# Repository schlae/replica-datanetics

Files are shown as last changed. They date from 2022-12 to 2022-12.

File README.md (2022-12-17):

# Replica Datanetics Keyboard

Do you need a Datanetics ASCII keyboard for your computer project (such as a replica Apple 1)? Don't want to pay high prices for an original Datanetics keyboard? Then consider building this replica.

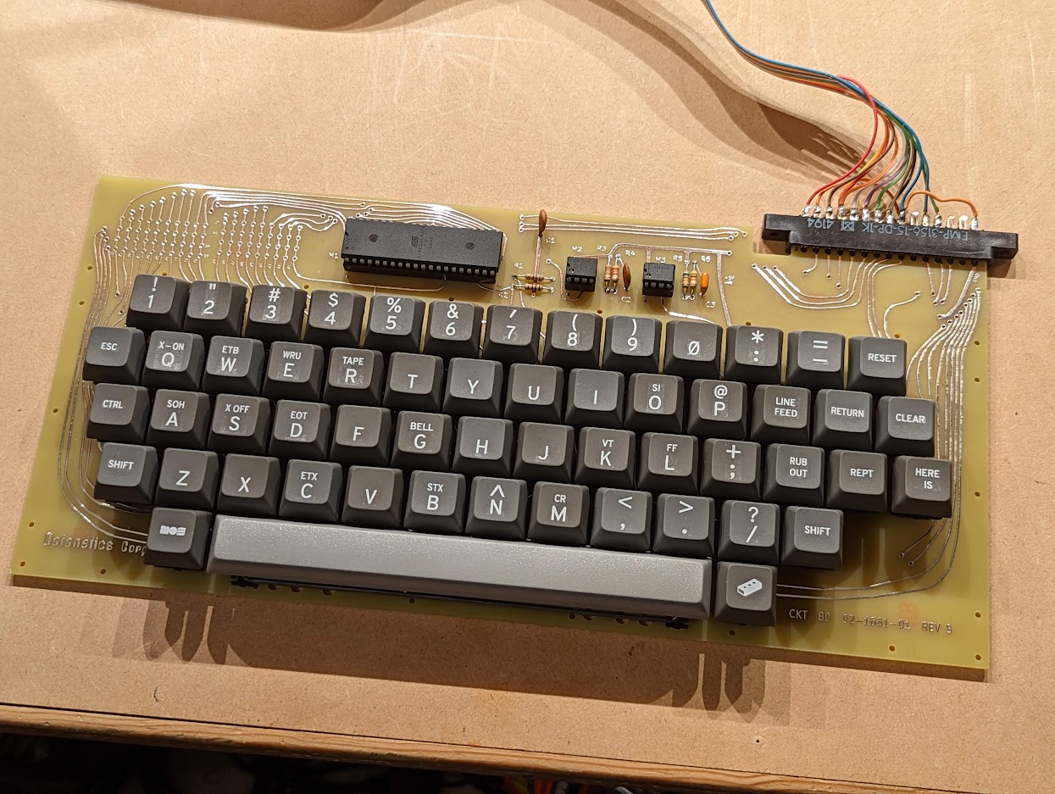
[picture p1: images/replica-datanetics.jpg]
Replica Datanetics keyboard photo


This is not the first replica Datanetics keyboard. Mike Willegal [designed one](http://www.willegal.net/appleii/apple1-datanetics.htm). In fact, I started with his design and redid it using KiCad. Instead of using the expensive, fragile, and hard-to-find MM5740 keyboard chip, I switched to a more common microcontroller: the ATMega644P. I also removed the output buffer chips--just in case you want to redo my firmware and implement some other keyboard protocol, you'll be able to control the pin direction.

Here are the design files. The BOM does not include manufacturer part numbers because it uses very common through hole parts that you might already have. The key switches are standard Cherry MX and are available from a wide variety of sources.

[Schematic](https://github.com/schlae/replica-datanetics/blob/main/Apple1Keyb.pdf)

[Bill of Materials](https://github.com/schlae/replica-datanetics/blob/main/Apple1Keyb.csv)

[Fab Files](https://github.com/schlae/replica-datanetics/blob/main/fab/Apple1Keyb_Rev1.zip)

[Water Slide Decal Graphics](https://github.com/schlae/replica-datanetics/blob/main/keycaps.svg)

## Fabrication and Assembly Notes

The circuit board is a 2-layer board, 11.75 by 5.5 inches (298.5 x 139.7mm). No special edge connector plating or bevel is needed. To make the board look like the original, order the board "bare bones" with no solder mask or silkscreen.

**Caution: There is a "matrix" via area in the upper left corner of the board with 76 non-plated vias. The drill locations for these are included in the "Apple1Keyb-NPTH.drl" file in the fab package. The User Comments layer also includes a note to the fab vendor to NOT plate these holes. You may want to add an extra comment to your fab vendor when you put in the order that these 76 holes must not be plated.**

To assemble the board, just solder in the components. I'd recommend using a socket for the U1 microcontroller so that you can reprogram it later. The NE555 timer (U2) in the original design was meant to provide the clock for the MM5740 chip, but isn't necessary in this design. You can install it or leave it out.

The second NE555 timer (U3) is necessary for the key repeat function.

## Key Caps

The keyboard design uses standard Cherry MX key switches and keycaps are available from numerous sources. For my own build, I used DSA keycaps along with an 8U spacebar from PMK. I looked into a number of ways of putting the legends on the keycaps but I ended up having some water slide decals custom made. See the file above if you want to use this same file, but I'd recommend putting the legends closer together so they'll fit on a smaller sheet, saving you money.

## Matrix Via Area

The Datanetics design has four key switches that are not connected to the key scanning matrix and are brought out to individual pins on the edge connector. If you're building an Apple 1, you'll want to use two of these keys for the reset and clear screen functions. 

If you want keys to be included in the scanning matrix, you'll want to solder a fine wire through the appropriate via in the upper left corner of the board. To find out which key will be generated, look up the row and column number in the key\_rom array in firmware source code. You can, of course, customize the generated key by editing the source and recompiling.

## Firmware

The firmware is designed for the ATMega644P microcontroller, but it should be possible to modify it to work with other 40-pin microcontrollers in the ATMega family. The prebuilt firmware behaves like a stock MM5740.

[Prebuilt Firmware](https://github.com/schlae/replica-datanetics/blob/main/fw/apple1keyb.hex)

Be sure to set the fuse bits of the ATMega644P according to the fuses.conf file:

```
lfuse = 0x62
hfuse = 0xdd
efuse = 0xfc
```

You can build the firmware yourself pretty easily. Under Ubuntu, install the `gcc-avr` package, and build the firmware by going to the directory and typing `make`.

If you have a minipro programmer (TL866 etc) you can program the device by typing `make fuses` followed by `make prog`. For this to work correctly, you'll need the [minipro software](https://gitlab.com/DavidGriffith/minipro) installed. You could also use the Windows minipro software from the manufacturer, or another programmer entirely.

## Mechanical Brackets

[Mike Willegal's site](http://www.willegal.net/appleii/apple1-datanetics.htm) has drawings for a mechanical bracket.

## Connecting to an Apple 1

If you want to connect this keyboard to an Apple 1, you can use the following wiring diagram. The connector to use is a 30-pin 0.156" edge connector, something like EDAC 305-030-520-202 or equivalent. The DIP plug is an insulation displacement connector, something like CW CWR-130-16-0001 or equivalent.

| Edge connector pin | Description | DIP plug pin |
|---|---|---|
| A | No connect (was -12V) | 11 (-12V) |
| B | Data bit 6 | 7 (B6) |
| C | Data bit 5 | 6 (B5) |
| D | Data bit 4 | 2 (B4) |
| E | Data bit 1 | 5 (B1) |
| F | Data bit 2 | 4 (B2) |
| H | Data bit 3 | 3 (B3) |
| J | Reset key | 1 (Reset) |
| K | Reset key | 9 (Gnd) |
| L | No connect (was OE) | No connect |
| M | Strobe | 14 (Str) |
| N | Data bit 7 | 8 (B7) |
| P | Data bit 8 | No connect |
| R | No connect (was data bit 9) | No connect |
| S | Ground | 9 |
| 1 | No connect | |
| 2 | No connect | |
| 3 | No connect | |
| 4 | +5V | 15, 16 |
| 5 | No connect | |
| 6 | No connect | |
| 7 | No connect | |
| 8 | Extra key 4 | 12 (Clr) |
| 9 | Extra key 4 | 16 |
| 10 | Extra key 3 | |
| 11 | Extra key 3 | |
| 12 | Extra key 1 | |
| 13 | Extra key 1 | |
| 14 | Extra key 2 | |
| 15 | Extra key 2 | |

## License
This work is licensed under a Creative Commons Attribution-ShareAlike 4.0
International License. See [https://creativecommons.org/licenses/by-sa/4.0/](https://creativecommons.org/licenses/by-sa/4.0/).

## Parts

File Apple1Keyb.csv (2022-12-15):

Item | Qty | Reference(s) | Value
1 | 1 | C1 | 0.1uF
2 | 1 | C2 | 0.01uF
3 | 1 | C3 | 0.68uF
4 | 2 | R1, R2 | 100
5 | 1 | R3 | 360
6 | 1 | R4 | 3.6K
7 | 1 | R5 | 510K
8 | 1 | R6 | 30K
9 | 56 | SW1-SW56 | Cherry MX keyswitch
10 | 2 |  | Cherry MX spacebar stabilizer
11 | 1 | U1 | ATmega644P-20P
12 | 2 | U2, U3 | NE555P

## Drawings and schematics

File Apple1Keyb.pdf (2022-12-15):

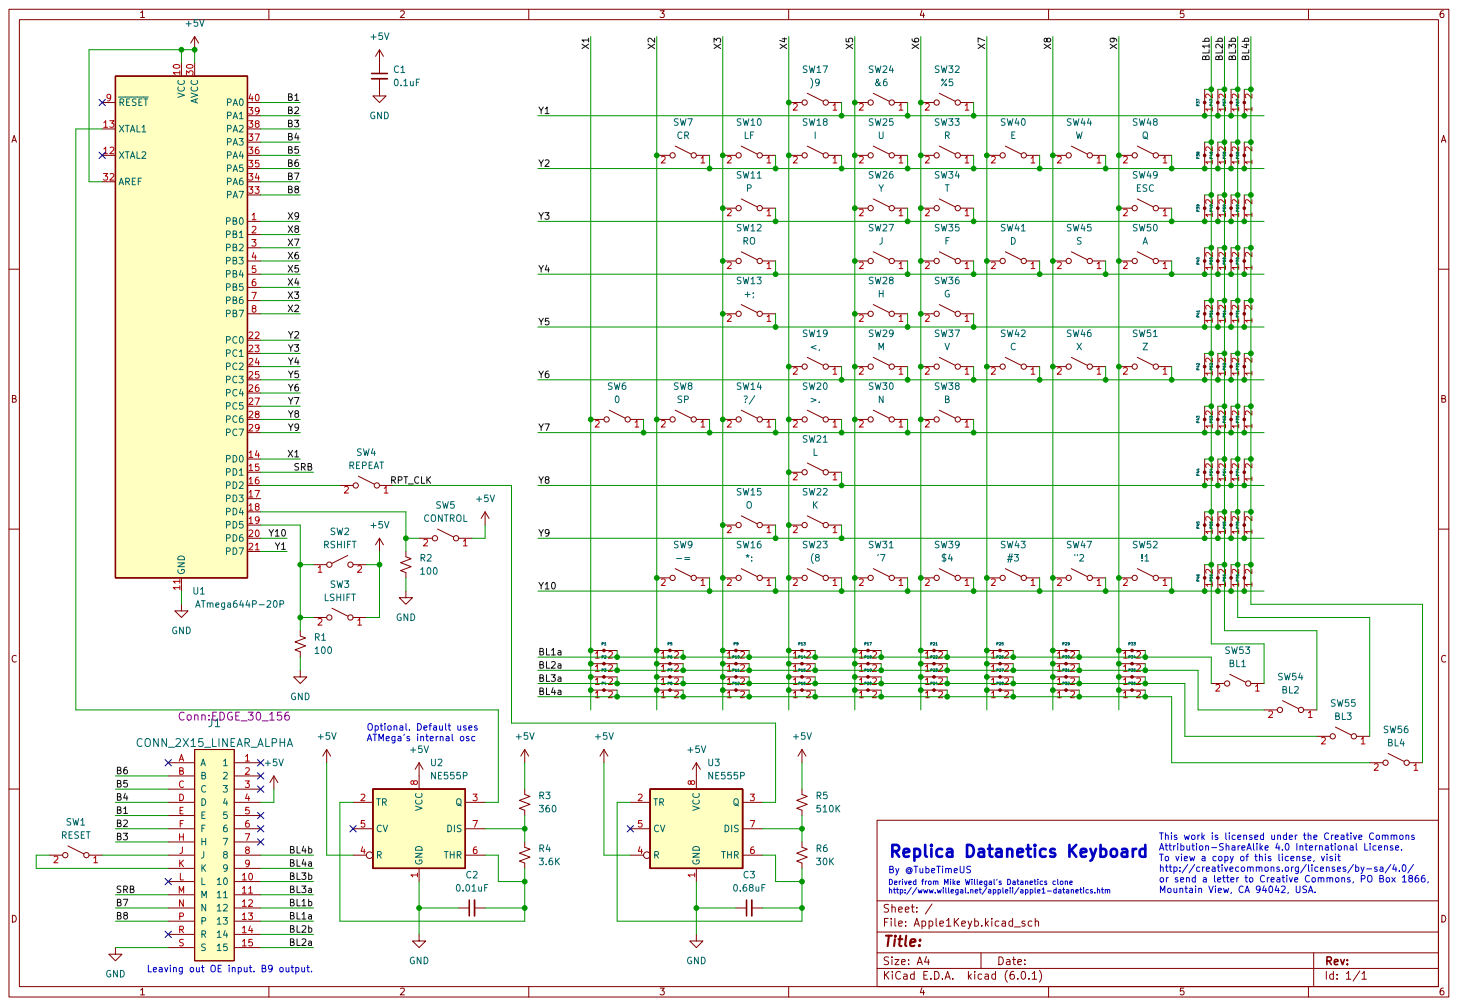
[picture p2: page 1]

This work is licensed under the Creative Commons Attribution-ShareAlike 4.0 International License. To view a copy of this license, visit

http://www.willegal.net/appleii/apple1-datanetics.htm By @TubeTimeUS

http://creativecommons.org/licenses/by-sa/4.0/ or send a letter to Creative Commons, PO Box 1866, Mountain View, CA 94042, USA.

Leaving out OE input. B9 output.

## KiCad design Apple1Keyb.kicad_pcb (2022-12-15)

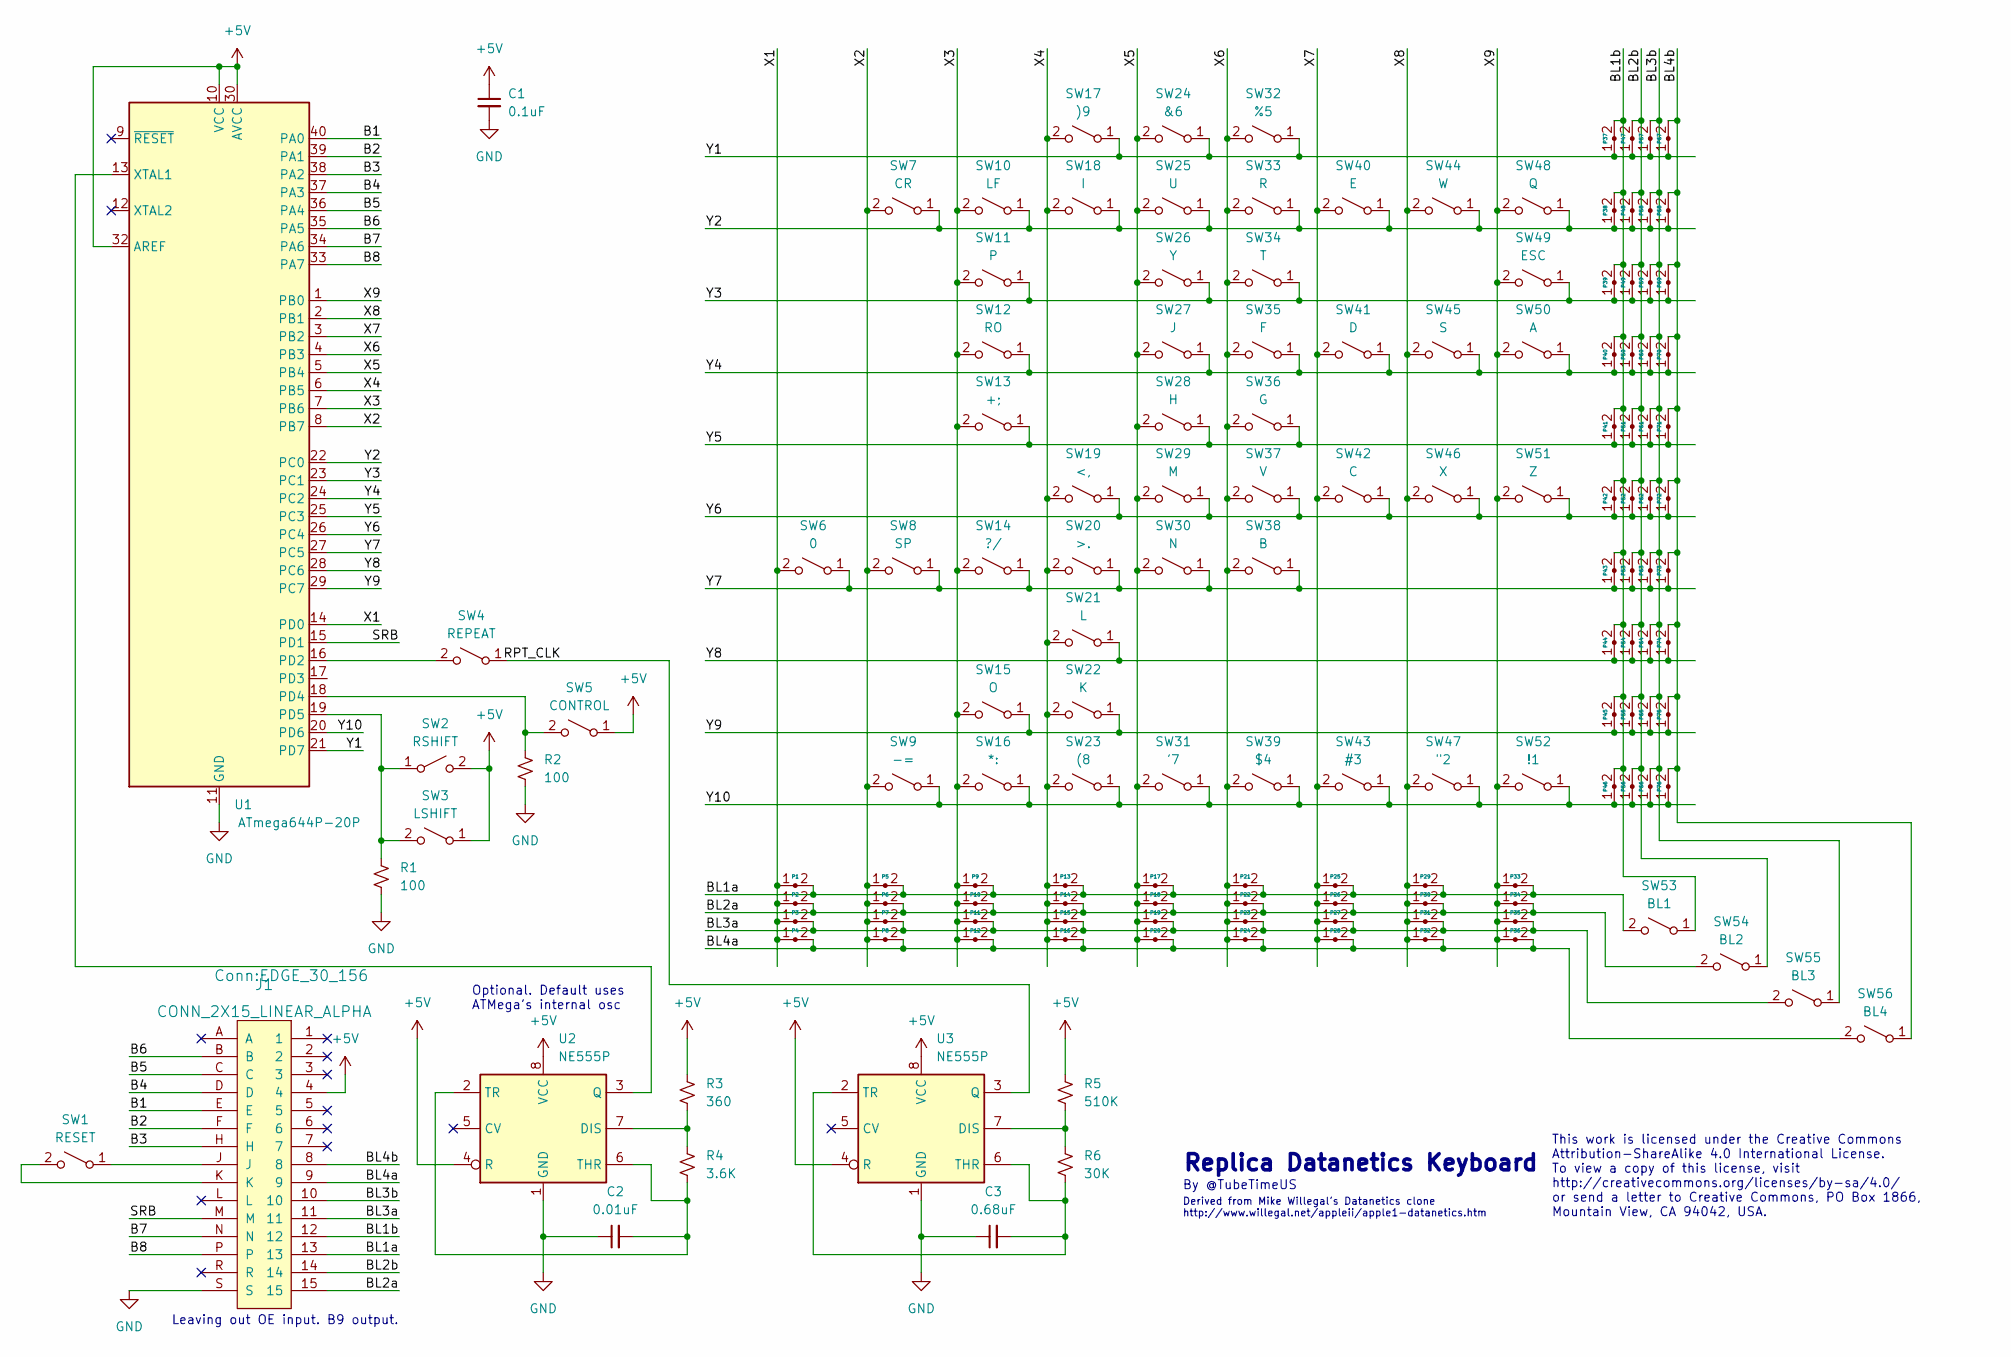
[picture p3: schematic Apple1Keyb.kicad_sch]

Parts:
C1: 0.1uF; C_Disc_D0.2in_W0.1in_P0.2in
C2: 0.01uF; C_Disc_D0.2in_W0.1in_P0.2in
C3: 0.68uF; C_Disc_D0.2in_W0.1in_P0.2in
J1: CONN_2X15_LINEAR_ALPHA; EDGE_30_156
P1, P2, P3, P4, P5, P6, P7, P8, P9, P10, P11, P12, P13, P14, P15, P16, P17, P18, P19, P20, P21, P22, P23, P24, P25, P26, P27, P28, P29, P30, P31, P32, P33, P34, P35, P36, P37, P38, P39, P40, P41, P42, P43, P44, P45, P46, P47, P48, P49, P50, P51, P52, P53, P54, P55, P56, P57, P58, P59, P60, P61, P62, P63, P64, P65, P66, P67, P68, P69, P70, P71, P72, P73, P74, P75, P76: jumper_pth; ViaNoPlate
R1, R2: 100; RESA500
R3: 360; RESA500
R4: 3.6K; RESA500
R5: 510K; RESA500
R6: 30K; RESA500
SW1: RESET; CHERRY_MX
SW2: RSHIFT; CHERRY_MX
SW3: LSHIFT; CHERRY_MX
SW4: REPEAT; CHERRY_MX
SW5: CONTROL; CHERRY_MX
SW6: 0; CHERRY_MX
SW7: CR; CHERRY_MX
SW8: SP; CHERRY_MX
SW9: -=; CHERRY_MX
SW10: LF; CHERRY_MX
SW11: P; CHERRY_MX
SW12: RO; CHERRY_MX
SW13: +;; CHERRY_MX
SW14: ?/; CHERRY_MX
SW15: O; CHERRY_MX
SW16: *:; CHERRY_MX
SW17: )9; CHERRY_MX
SW18: I; CHERRY_MX
SW19: <,; CHERRY_MX
SW20: >.; CHERRY_MX
SW21: L; CHERRY_MX
SW22: K; CHERRY_MX
SW23: (8; CHERRY_MX
SW24: &6; CHERRY_MX
SW25: U; CHERRY_MX
SW26: Y; CHERRY_MX
SW27: J; CHERRY_MX
SW28: H; CHERRY_MX
SW29: M; CHERRY_MX
SW30: N; CHERRY_MX
SW31: '7; CHERRY_MX
SW32: %5; CHERRY_MX
SW33: R; CHERRY_MX
SW34: T; CHERRY_MX
SW35: F; CHERRY_MX
SW36: G; CHERRY_MX
SW37: V; CHERRY_MX
SW38: B; CHERRY_MX
SW39: $4; CHERRY_MX
SW40: E; CHERRY_MX
SW41: D; CHERRY_MX
SW42: C; CHERRY_MX
SW43: #3; CHERRY_MX
SW44: W; CHERRY_MX
SW45: S; CHERRY_MX
SW46: X; CHERRY_MX
SW47: "2; CHERRY_MX
SW48: Q; CHERRY_MX
SW49: ESC; CHERRY_MX
SW50: A; CHERRY_MX
SW51: Z; CHERRY_MX
SW52: !1; CHERRY_MX
SW53: BL1; CHERRY_MX
SW54: BL2; CHERRY_MX
SW55: BL3; CHERRY_MX
SW56: BL4; CHERRY_MX
U1: ATmega644P-20P; DIP-40_W15.24mm
U2, U3: NE555P; DIP-8_W7.62mm

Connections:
+5V: C1.1, J1.4, R3.2, R5.2, SW2.2 (B), SW3.1 (A), SW5.1 (A), U1.10 (VCC), U1.30 (AVCC), U1.32 (AREF), U2.4 (R), U2.8 (VCC), U3.4 (R), U3.8 (VCC)
/B1: J1.E, U1.40 (PA0)
/B2: J1.F, U1.39 (PA1)
/B3: J1.H, U1.38 (PA2)
/B4: J1.D, U1.37 (PA3)
/B5: J1.C, U1.36 (PA4)
/B6: J1.B, U1.35 (PA5)
/B7: J1.N, U1.34 (PA6)
/B8: J1.P, U1.33 (PA7)
/BL1a: J1.13, P1.2, P5.2, P9.2, P13.2, P17.2, P21.2, P25.2, P29.2, P33.2, SW53.2 (B)
/BL1b: J1.12, P37.2, P38.2, P39.2, P40.2, P41.2, P42.2, P43.2, P44.2, P45.2, P46.2, SW53.1 (A)
/BL2a: J1.15, P2.2, P6.2, P10.2, P14.2, P18.2, P22.2, P26.2, P30.2, P34.2, SW54.2 (B)
/BL2b: J1.14, P47.2, P48.2, P49.2, P50.2, P51.2, P52.2, P53.2, P54.2, P55.2, P56.2, SW54.1 (A)
/BL3a: J1.11, P3.2, P7.2, P11.2, P15.2, P19.2, P23.2, P27.2, P31.2, P35.2, SW55.2 (B)
/BL3b: J1.10, P57.2, P58.2, P59.2, P60.2, P61.2, P62.2, P63.2, P64.2, P65.2, P66.2, SW55.1 (A)
/BL4a: J1.9, P4.2, P8.2, P12.2, P16.2, P20.2, P24.2, P28.2, P32.2, P36.2, SW56.2 (B)
/BL4b: J1.8, P67.2, P68.2, P69.2, P70.2, P71.2, P72.2, P73.2, P74.2, P75.2, P76.2, SW56.1 (A)
/RPT_CLK: SW4.1 (A), U3.3 (Q)
/SRB: J1.M, U1.15 (PD1)
/X1: P1.1, P2.1, P3.1, P4.1, SW6.2 (B), U1.14 (PD0)
/X2: P5.1, P6.1, P7.1, P8.1, SW7.2 (B), SW8.2 (B), SW9.2 (B), U1.8 (PB7)
/X3: P9.1, P10.1, P11.1, P12.1, SW10.2 (B), SW11.2 (B), SW12.2 (B), SW13.2 (B), SW14.2 (B), SW15.2 (B), SW16.2 (B), U1.7 (PB6)
/X4: P13.1, P14.1, P15.1, P16.1, SW17.2 (B), SW18.2 (B), SW19.2 (B), SW20.2 (B), SW21.2 (B), SW22.2 (B), SW23.2 (B), U1.6 (PB5)
/X5: P17.1, P18.1, P19.1, P20.1, SW24.2 (B), SW25.2 (B), SW26.2 (B), SW27.2 (B), SW28.2 (B), SW29.2 (B), SW30.2 (B), SW31.2 (B), U1.5 (PB4)
/X6: P21.1, P22.1, P23.1, P24.1, SW32.2 (B), SW33.2 (B), SW34.2 (B), SW35.2 (B), SW36.2 (B), SW37.2 (B), SW38.2 (B), SW39.2 (B), U1.4 (PB3)
/X7: P25.1, P26.1, P27.1, P28.1, SW40.2 (B), SW41.2 (B), SW42.2 (B), SW43.2 (B), U1.3 (PB2)
/X8: P29.1, P30.1, P31.1, P32.1, SW44.2 (B), SW45.2 (B), SW46.2 (B), SW47.2 (B), U1.2 (PB1)
/X9: P33.1, P34.1, P35.1, P36.1, SW48.2 (B), SW49.2 (B), SW50.2 (B), SW51.2 (B), SW52.2 (B), U1.1 (PB0)
/Y1: P37.1, P47.1, P57.1, P67.1, SW17.1 (A), SW24.1 (A), SW32.1 (A), U1.21 (PD7)
/Y2: P38.1, P48.1, P58.1, P68.1, SW7.1 (A), SW10.1 (A), SW18.1 (A), SW25.1 (A), SW33.1 (A), SW40.1 (A), SW44.1 (A), SW48.1 (A), U1.22 (PC0)
/Y3: P39.1, P49.1, P59.1, P69.1, SW11.1 (A), SW26.1 (A), SW34.1 (A), SW49.1 (A), U1.23 (PC1)
/Y4: P40.1, P50.1, P60.1, P70.1, SW12.1 (A), SW27.1 (A), SW35.1 (A), SW41.1 (A), SW45.1 (A), SW50.1 (A), U1.24 (PC2)
/Y5: P41.1, P51.1, P61.1, P71.1, SW13.1 (A), SW28.1 (A), SW36.1 (A), U1.25 (PC3)
/Y6: P42.1, P52.1, P62.1, P72.1, SW19.1 (A), SW29.1 (A), SW37.1 (A), SW42.1 (A), SW46.1 (A), SW51.1 (A), U1.26 (PC4)
/Y7: P43.1, P53.1, P63.1, P73.1, SW6.1 (A), SW8.1 (A), SW14.1 (A), SW20.1 (A), SW30.1 (A), SW38.1 (A), U1.27 (PC5)
/Y8: P44.1, P54.1, P64.1, P74.1, SW21.1 (A), U1.28 (PC6)
/Y9: P45.1, P55.1, P65.1, P75.1, SW15.1 (A), SW22.1 (A), U1.29 (PC7)
/Y10: P46.1, P56.1, P66.1, P76.1, SW9.1 (A), SW16.1 (A), SW23.1 (A), SW31.1 (A), SW39.1 (A), SW43.1 (A), SW47.1 (A), SW52.1 (A), U1.20 (PD6)
GND: C1.2, C2.1, C3.1, J1.S, R1.1, R2.1, U1.11 (GND), U1.31 (GND), U2.1 (GND), U3.1 (GND)
unnamed: C2.2, R4.1, U2.2 (TR), U2.6 (THR)
unnamed: C3.2, R6.1, U3.2 (TR), U3.6 (THR)
unnamed: J1.J, SW1.1 (A)
unnamed: J1.K, SW1.2 (B)
unnamed: R1.2, SW2.1 (A), SW3.2 (B), U1.19 (PD5)
unnamed: R2.2, SW5.2 (B), U1.18 (PD4)
unnamed: R3.1, R4.2, U2.7 (DIS)
unnamed: R5.1, R6.2, U3.7 (DIS)
unnamed: SW4.2 (B), U1.16 (PD2)
unnamed: U1.13 (XTAL1), U2.3 (Q)

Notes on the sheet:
By @TubeTimeUS
Leaving out OE input. B9 output.
Optional. Default uses ATMega's internal osc
Derived from Mike Willegal's Datanetics clone http://www.willegal.net/appleii/apple1-datanetics.htm
Replica Datanetics Keyboard
This work is licensed under the Creative Commons Attribution-ShareAlike 4.0 International License. To view a copy of this license, visit http://creativecommons.org/licenses/by-sa/4.0/ or send a letter to Creative Commons, PO Box 1866, Mountain View, CA 94042, USA.

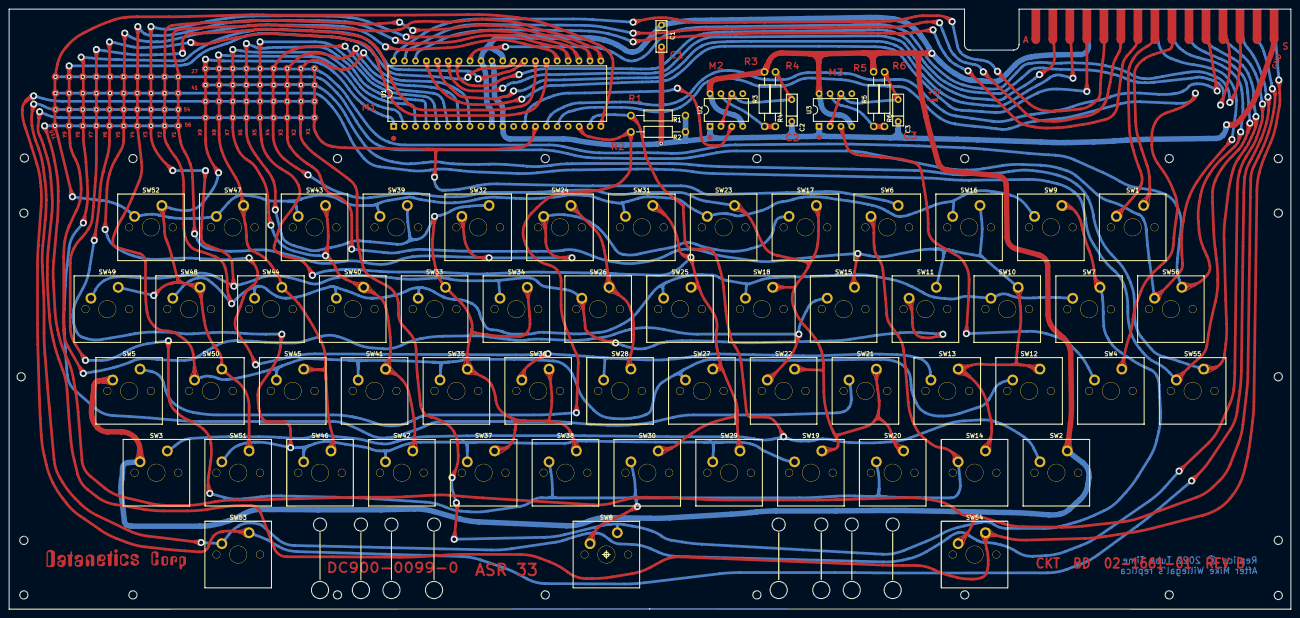
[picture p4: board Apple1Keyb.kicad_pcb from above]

Board: 2 copper layers, 298.4 x 139.7 mm, 169 parts (1 on the bottom side), 49 nets.

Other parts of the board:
G1: LOGO; Datanetics
MH1, MH2, MH3, MH4, MH5, MH6, MH7, MH8, MH9, MH10, MH11, MH12, MH13, MH14, MH15, MH16, MH17, MH18, MH19, MH20, MH21, MH22: MountHole
ST1: CHERRY_ST3

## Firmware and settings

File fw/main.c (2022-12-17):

/* MM5740 equivalent clone, copyright (C) 2022 Tube Time.

   This work is licensed under the Creative Commons Attribution-ShareAlike 4.0
   International License. To view a copy of this license, visit
   http://creativecommons.org/licenses/by-sa/4.0/ or send a letter to
   Creative Commons, PO Box 1866, Mountain View, CA 94042, USA.
*/

#include <stdbool.h>
#include <avr/io.h>
#include <util/delay.h>


/* Port assignments:
    PORTA = External data port (outputs)
    PORTB
        0 - X9
        1 - X8
        2 - X7
        3 - X6
        4 - X5
        5 - X4
        6 - X3
        7 - X2
    PORTC
        0 - Y2
        1 - Y3
        2 - Y4
        3 - Y5
        4 - Y6
        5 - Y7
        6 - Y8
        7 - Y9
    PORTD
        0 - X1
        1 - SRB (strobe output)
        2 - Repeat clock in
        3 - n/c
        4 - Control key
        5 - Shift key
        6 - Y10
        7 - Y1
*/

#define KEY_COUNT           90  // Total number of possible keys
#define DEBOUNCE_DELAY     200  // 2ms debounce delay
#define STROBE_TIME         50  // 50us strobe pulse
#define ROW_SETTLING_TIME   50  // 50us settling time

bool keyflags[KEY_COUNT] = {0};
bool repeat_history = false;

uint8_t key_rom[] = {
// Row
// 1     2     3     4     5     6     7     8     9   10
// Unshifted
 '8',  '4',  '5',  '1',  '2',  '3',  '0',  '6',  '9', '7', // Col 1
0x0c, 0x0d, 0x1c, 0x1d, 0x0b, 0x0e, 0x20, 0x09, 0x08, '-', // Col 2
 '0', 0x0a,  'P', 0x7f,  ';',  '.',  '/',  'P',  'O', ':', // Col 3
 '9',  'I',  'O',  'K',  'L',  ',',  '.',  'L',  'K', '8', // Col 4
 '6',  'U',  'Y',  'J',  'H',  'M',  'N',  'M',  'N', '7', // Col 5
 '5',  'R',  'T',  'F',  'G',  'V',  'B', 0x18, 0x19, '4', // Col 6
0x12,  'E', 0x13,  'D', 0x14,  'C', 0x15, 0x16, 0x17, '3', // Col 7
0x05,  'W', 0x06,  'S', 0x07,  'X', 0x0f, 0x10, 0x11, '2', // Col 8
0x00,  'Q', 0x1b,  'A', 0x01,  'Z', 0x02, 0x03, 0x04, '1', // Col 9

// Shifted
 '8',  '4',  '5',  '1',  '2',  '3',  '0',  '6',  '9', '7', // Col 1
0x0c, 0x0d, 0x1c, 0x1d, 0x0b, 0x0e, 0x20, 0x09, 0x08, '=', // Col 2
 '0', 0x0a,  '@', 0x7f,  '+',  '.',  '?',  'P',  'O', '*', // Col 3
 ')',  'I',  '_',  '[', 0x5c,  '<',  '>',  'L',  'K', '(', // Col 4
 '&',  'U',  'Y',  'J',  'H',  ']',  '^',  'M',  'N',0x27, // Col 5
 '%',  'R',  'T',  'F',  'G',  'V',  'B', 0x18, 0x19, '$', // Col 6
0x12,  'E', 0x13,  'D', 0x14,  'C', 0x15, 0x16, 0x17, '#', // Col 7
0x05,  'W', 0x06,  'S', 0x07,  'X', 0x0f, 0x10, 0x11,0x22, // Col 8
0x00,  'Q', 0x1b,  'A', 0x01,  'Z', 0x02, 0x03, 0x04, '!', // Col 9

// Control
 '8',  '4',  '5',  '1',  '2',  '3',  '0',  '6',  '9', '7', // Col 1
0x0c, 0x0d, 0x1c, 0x1d, 0x0b, 0x0e, 0x20, 0x09, 0x08, '-', // Col 2
 '0', 0x0a,  'P', 0x7f,  ';',  '.',  '/', 0x10, 0x0f, ':', // Col 3
 '9', 0x09, 0x0f, 0x0b, 0x0c,  ',',  '.', 0x0c, 0x0b, '8', // Col 4
 '6', 0x15, 0x19, 0x0a, 0x08, 0x0d, 0x0e, 0x0d, 0x0e, '7', // Col 5
 '5', 0x12, 0x14, 0x06, 0x07, 0x16, 0x02, 0x18, 0x19, '4', // Col 6
0x12, 0x05, 0x13, 0x04, 0x14, 0x03, 0x15, 0x16, 0x17, '3', // Col 7
0x05, 0x17, 0x06, 0x13, 0x07, 0x18, 0x0F, 0x10, 0x11, '2', // Col 8
0x00, 0x11, 0x1b, 0x01, 0x01, 0x1a, 0x02, 0x03, 0x04, '1', // Col 9

// Shift + Control
 '8',  '4',  '5',  '1',  '2',  '3',  '0',  '6',  '9', '7', // Col 1
0x0c, 0x0d, 0x1c, 0x1d, 0x0b, 0x0e, 0x20, 0x09, 0x08, '=', // Col 2
 '0', 0x0a, 0x00, 0x7f,  '+',  '.',  '?', 0x10, 0x0f, '*', // Col 3
 ')', 0x09, 0x1f, 0x1b, 0x1c,  '<',  '>', 0x0c, 0x0b, '(', // Col 4
 '&', 0x15, 0x19, 0x0a, 0x08, 0x1d, 0x1e, 0x0d, 0x0e,0x27, // Col 5
 '%', 0x12, 0x14, 0x06, 0x07, 0x16, 0x02, 0x18, 0x19, '$', // Col 6
0x12, 0x05, 0x13, 0x04, 0x14, 0x03, 0x15, 0x16, 0x17, '#', // Col 7
0x05, 0x17, 0x06, 0x13, 0x07, 0x18, 0x0F, 0x10, 0x11,0x22, // Col 8
0x00, 0x11, 0x1b, 0x01, 0x01, 0x1a, 0x02, 0x03, 0x04, '!', // Col 9


};

// Output Bit changes for ROM:
// 1, 2, 3, 4,  ,  ,  ,
//             5, 6, 7, 8    - changes for ctrl and shift


// Disables the drive signal on a X column
void disable_column(uint8_t col)
{
    // Disable the current column
    if (col == 0) {
        DDRD &= ~_BV(0);
    } else {
        DDRB &= ~_BV(8 - col);
    }
}

// Enables the drive signal on a X column
void enable_column(uint8_t col)
{
    // Enable the next column
    if (col == 0) {
        DDRD |= _BV(0);
    } else {
        DDRB |= _BV(8 - col);
    }
}

// Read the contents of the Y rows.
uint16_t read_rows()
{
    return ~((((uint16_t)PIND & 0x40) << 3) |
              ((uint16_t)PINC << 1) |
              ((uint16_t)PIND >> 7));
}

// Pulse the strobe output
void strobe()
{
    PORTD |= _BV(1);
    _delay_us(STROBE_TIME);
    PORTD &= ~_BV(1);
}

// Checks for falling edge on the key repeat signal
bool is_repeat()
{
    bool repeat = (PIND & _BV(2));
    if (!repeat && repeat_history) {
        repeat_history = repeat;
        return true;
    } else {
        repeat_history = repeat;
        return false;
    }
}

// Checks a key in a row to ensure it stays down
bool debounce_key(uint8_t row)
{
    int debounce;
    for (debounce = 0; debounce < DEBOUNCE_DELAY; debounce++) {
        _delay_us(10);
        if (!(read_rows() & _BV(row))) {
            return false;
        }
    }
    return true;
}

// Look up the key in the ROM, with shift and control
uint8_t key_lookup(uint8_t scancode)
{
    uint16_t shift = (PIND & _BV(5)) ? 90 : 0;
    uint16_t control = (PIND & _BV(4)) ? 180: 0;
    return key_rom[(uint16_t)scancode + shift + control];
}

// Scan the keyboard matrix
bool scan_keys()
{
    uint8_t x, y, rom_addr, debounce;
    uint16_t row_data;
    bool keydown = false;

    rom_addr = 0;
    for (x = 0; x < 9; x++) {
        enable_column(x);
        _delay_us(ROW_SETTLING_TIME);
        row_data = read_rows();
        // Sense logic also uses a counter.
        for (y = 0; y < 10; y++) {
            if (row_data & _BV(y)) {
                if (!keyflags[rom_addr] & debounce_key(y)) {
                    PORTA = key_lookup(rom_addr);
                    strobe();
                    keyflags[rom_addr] = true;  // Key is down, update memory so we don't emit it again

                    // Continue scanning for more keys
                }
            } else {
                keyflags[rom_addr] = false;  // Key is not down, update memory
            }
            // Detect if any key is down
            if (keyflags[rom_addr]) keydown = true;
            rom_addr++;
        }
        disable_column(x);
    }
    return keydown;
}

// Note: Emit strobe pulse for one clock period (around 50us).

void main(void)
{
    // Set up ports
    DDRA = 0xff; // Output port
    PORTA = 0x00; // No character

    DDRB = 0x00; // Column drivers (X) are off by default
    PORTB = 0x00; // No pullup resistors for column drivers

    DDRC = 0x00; // Row connections (Y) are inputs
    PORTC = 0xff; // Pullup resistors turned on

    DDRD = _BV(1) | _BV(3); // SRB and n/c are outputs
    PORTD = _BV(2) | _BV(6) | _BV(7); // Pullups for REPEAT, Y10 and Y1

    while(1) {
        if (scan_keys() && is_repeat()) {
            strobe(); // pulse strobe again
        }
    }
}

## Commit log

2022-12-15 Initial version.
    [Apple1Keyb.csv, Apple1Keyb.kicad_pcb, Apple1Keyb.kicad_sch]
2022-12-17 Add wiring for Apple 1

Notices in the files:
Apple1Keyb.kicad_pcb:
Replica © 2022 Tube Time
